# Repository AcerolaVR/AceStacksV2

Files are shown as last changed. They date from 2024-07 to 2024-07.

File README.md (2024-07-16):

# AceStacks v2
A compact, easy-to-assemble SlimeVR tracker design using a PCB with attached sensor and charge circuitry, and the commonly available 16340 battery.

# Overview
AceStacks V2 is a compact, easy-to-assemble SlimeVR tracker design using a PCB with attached sensor and charge circuitry, a D1 Mini, and the commonly available 16340 battery. Here are some of the standout features of the AceStacks trackers.

- The use of the included pin sockets of the D1 Mini allows the MCU to mount over other components, resulting in a compact PCB footprint.
- The design of the board reduces the number of pin headers that need to be trimmed, one of the more annoying parts of DIY trackers with PCBs.
- 16340 cells are easier to obtain (in the United States, not sure about the rest of the world), relatively cheap, more durable compared to li-po pouch cells, and hot swappable if you need more battery life
- This arrangement allows for a compact full body tracker with ~8 hours of battery life, battery sense, AUX tracker support, and a hot swappable battery.

# Parts
Refer to the Official SlimeVR Component Guide for more info https://docs.slimevr.dev/diy/components-guide.html

## Required Parts
- AceStacks V2 PCB
- Microcontroller: Wemos D1 Mini // https://www.aliexpress.com/w/wholesale-D1-mini.html
- Batteries: 16450 Li-ion Batteries // https://illumn.com/16340-vapcell-inr16340-t8-850mah-3a-high-discharge-button-top.html or https://liionwholesale.com/products/vapcell-t8-16340-rcr123a-3a-button-top-850mah-battery-genuine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
- Straps: 1.5in or 38mm Straps // https://www.aliexpress.us/item/3256801722425879.html or https://www.aliexpress.us/item/3256802873749389.html
- 3d Printed Cases

## Extension Parts
- JST ZH1.5 4P, Straight Pin to Pin // [https://www.aliexpress.us/item/3256802896025388.html](https://www.aliexpress.us/item/2251832672911708.html)
# Ordering
You can order bare PCBs here: https://ko-fi.com/s/a833b35730
You can order complete Acestacks V2 Kits Here: https://ko-fi.com/s/f68f3c7944

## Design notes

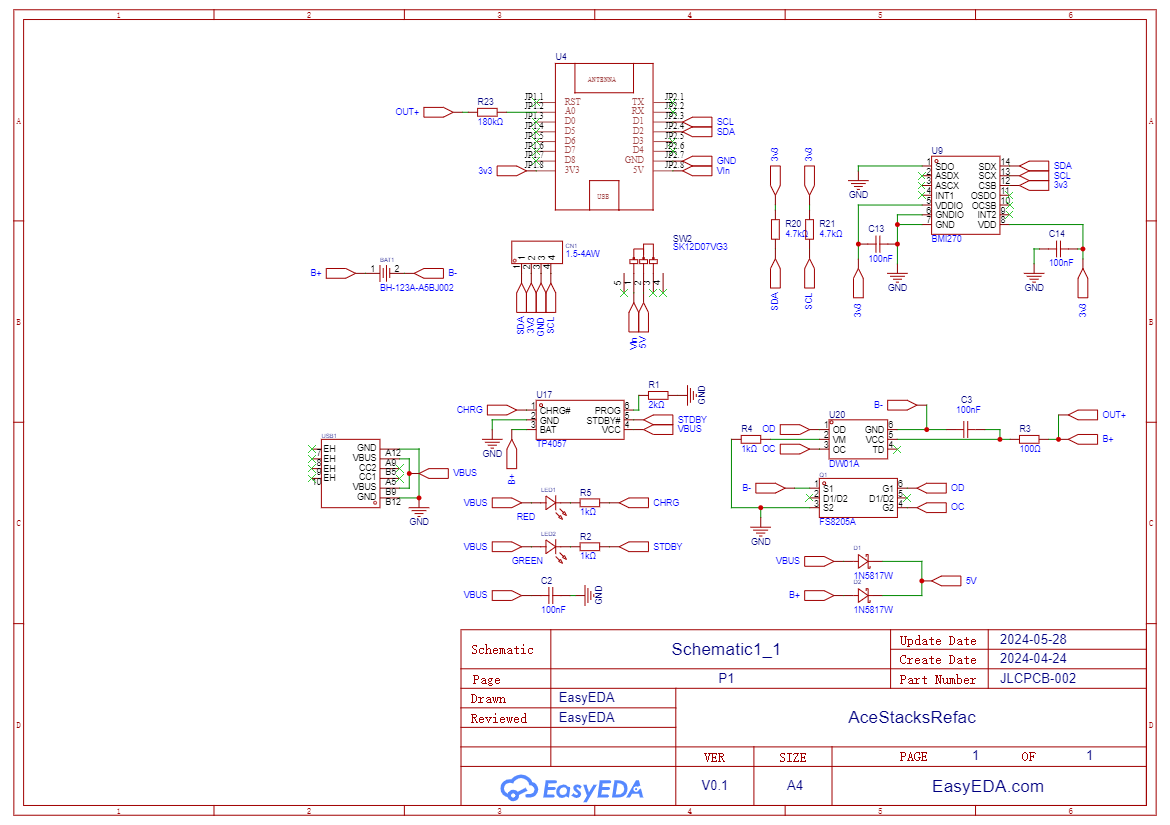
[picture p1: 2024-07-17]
SCHEMATIC/Schematic.png

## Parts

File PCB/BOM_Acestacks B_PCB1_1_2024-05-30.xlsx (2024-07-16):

No. | Quantity | Comment | Designator | Footprint | Value | Manufacturer Part | Manufacturer | Supplier Part | Supplier
1 | 1 | BH-123A-A5BJ002 | BAT1 | BAT-TH_BH-123A-A5BJ002 |  | BH-123A-A5BJ002 | MYOUNG(美阳) | C5290177 | LCSC
2 | 4 | 100nF | C2,C3,C13,C14 | C0603 | 100nF | CC0603KRX7R9BB104 | YAGEO(国巨) | C14663 | LCSC
3 | 1 | 1.5-4AW | CN1 | CONN-TH_4P-P1.50_ZH1.5-4AW |  | 1.5-4AW | BOOMELE(博穆精密) | C146006 | LCSC
4 | 2 | 1N5817W | D1,D2 | SOD-123_L2.8-W1.8-LS3.7-RD |  | 1N5817W | TWGMC(台湾迪嘉) | C727113 | LCSC
5 | 1 | RED | LED1 | LED0603-RD_RED |  | XL-1608SURC-06 | XINGLIGHT(成兴光) | C965799 | LCSC
6 | 1 | GREEN | LED2 | LED0603-RD_GREEN |  | XL-1608UGC-04 | XINGLIGHT(成兴光) | C965804 | LCSC
7 | 1 | FS8205A | Q1 | SOT-23-6_L2.9-W1.6-P0.95-LS2.8-BR |  | FS8205A | FUXINSEMI(富芯森美) | C908265 | LCSC
8 | 1 | 2kΩ | R1 | R0603 | 2kΩ | 0603WAF2001T5E | UNI-ROYAL(厚声) | C22975 | LCSC
9 | 3 | 1kΩ | R2,R4,R5 | R0603 | 1kΩ | 0603WAF1001T5E | UNI-ROYAL(厚声) | C21190 | LCSC
10 | 1 | 100Ω | R3 | R0603 | 100Ω | 0603WAF1000T5E | UNI-ROYAL(厚声) | C22775 | LCSC
11 | 2 | 4.7kΩ | R20,R21 | R0603 | 4.7kΩ | 0603WAF4701T5E | UNI-ROYAL(厚声) | C23162 | LCSC
12 | 1 | 180kΩ | R23 | R0603 | 180kΩ | RTT03184JTP | RALEC(旺诠) | C103362 | LCSC
13 | 1 | SK12D07VG3 | SW2 | SW-TH_SK12D07VG3 |  | SK12D07VG3 | SHOU HAN(首韩) | C431547 | LCSC
14 | 1 | D1-MINI | U4 | D1-MINI
15 | 1 | BMI270 | U9 | LGA-14_L3.0-W2.5-P0.50-BR |  | BMI270 | Bosch(博世) | C2836813 | LCSC
16 | 1 | TP4057 | U17 | SOT-23-6_L2.9-W1.6-P0.95-LS2.8-BR |  | TP4057 | UMW(友台半导体) | C725791 | LCSC
17 | 1 | DW01A | U20 | SOT-23-6_L2.9-W1.6-P0.95-LS2.8-BL |  | DW01A | PUOLOP(迪浦) | C351410 | LCSC
18 | 1 | U262-061N-4BVC11 | USB1 | USB-SMD_U262-061N-4BVC11 |  | U262-061N-4BVC11 | XKB Connectivity(中国星坤) | C2764612 | LCSC

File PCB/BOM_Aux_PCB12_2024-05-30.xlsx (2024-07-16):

No. | Quantity | Comment | Designator | Footprint | Value | Manufacturer Part | Manufacturer | Supplier Part | Supplier
1 | 2 | 100nF | C13,C14 | C0603 | 100nF | CC0603KRX7R9BB104 | YAGEO(国巨) | C14663 | LCSC
2 | 1 | 1.5-4AW | CN1 | CONN-TH_4P-P1.50_ZH1.5-4AW |  | 1.5-4AW | BOOMELE(博穆精密) | C146006 | LCSC
3 | 3 | 4.7kΩ | R20,R22,R23 | R0603 | 4.7kΩ | 0603WAF4701T5E | UNI-ROYAL(厚声) | C23162 | LCSC
4 | 1 | BMI270 | U9 | LGA-14_L3.0-W2.5-P0.50-BR |  | BMI270 | Bosch(博世) | C2836813 | LCSC

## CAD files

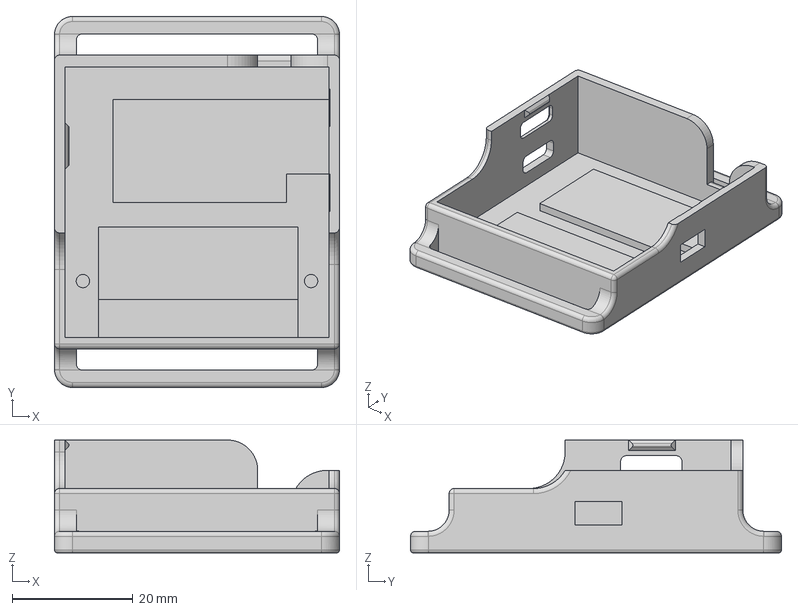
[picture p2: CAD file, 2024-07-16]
STEP/StandardCase.step
47.2 x 61.5 x 18.7 mm

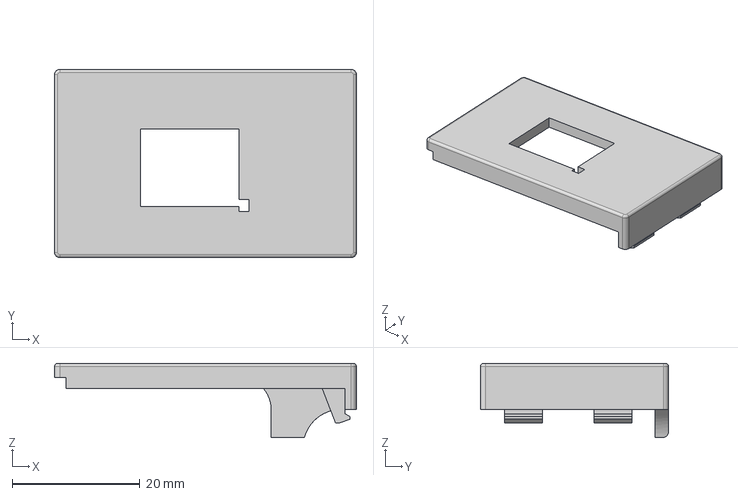
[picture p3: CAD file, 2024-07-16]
STEP/Lid.step
47.2 x 29.5 x 11.6 mm

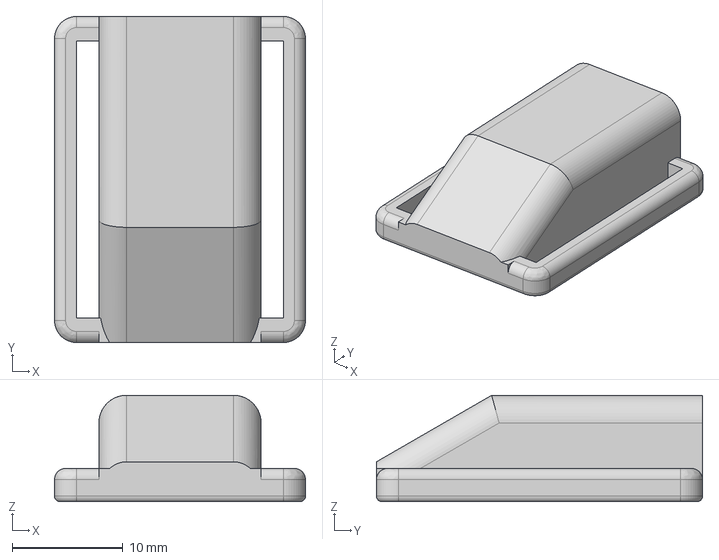
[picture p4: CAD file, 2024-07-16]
STEP/BMI270.step
22.6 x 29.4 x 9.60 mm

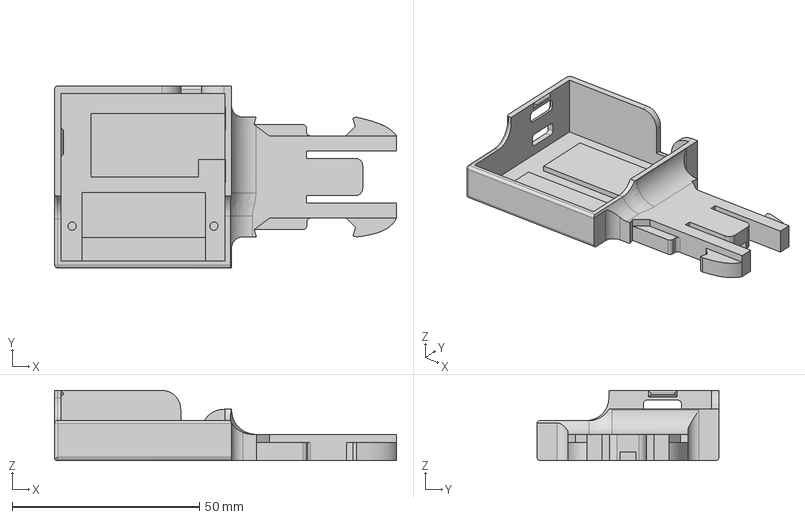
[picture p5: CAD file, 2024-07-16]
STEP/GoProCase.step
91.2 x 48.7 x 18.7 mm

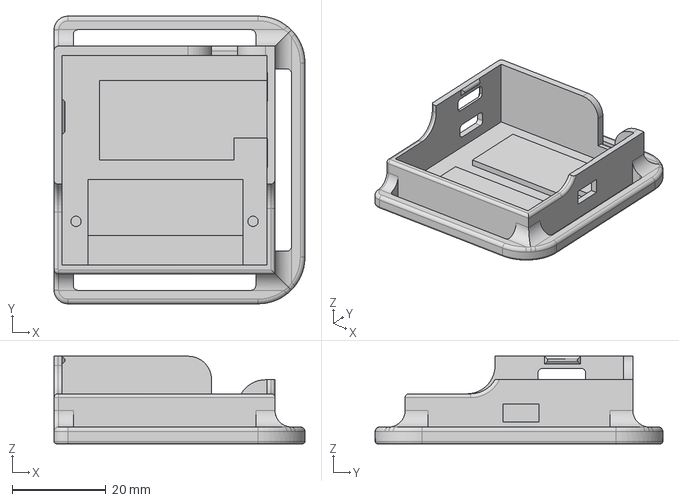
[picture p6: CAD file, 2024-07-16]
STEP/GarterCase.step
53.6 x 61.5 x 18.7 mm

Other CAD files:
STL/BMI270.stl
STL/GarterCase.stl
STL/GoProCase.stl
STL/Lid.stl
STL/StandardCase.stl

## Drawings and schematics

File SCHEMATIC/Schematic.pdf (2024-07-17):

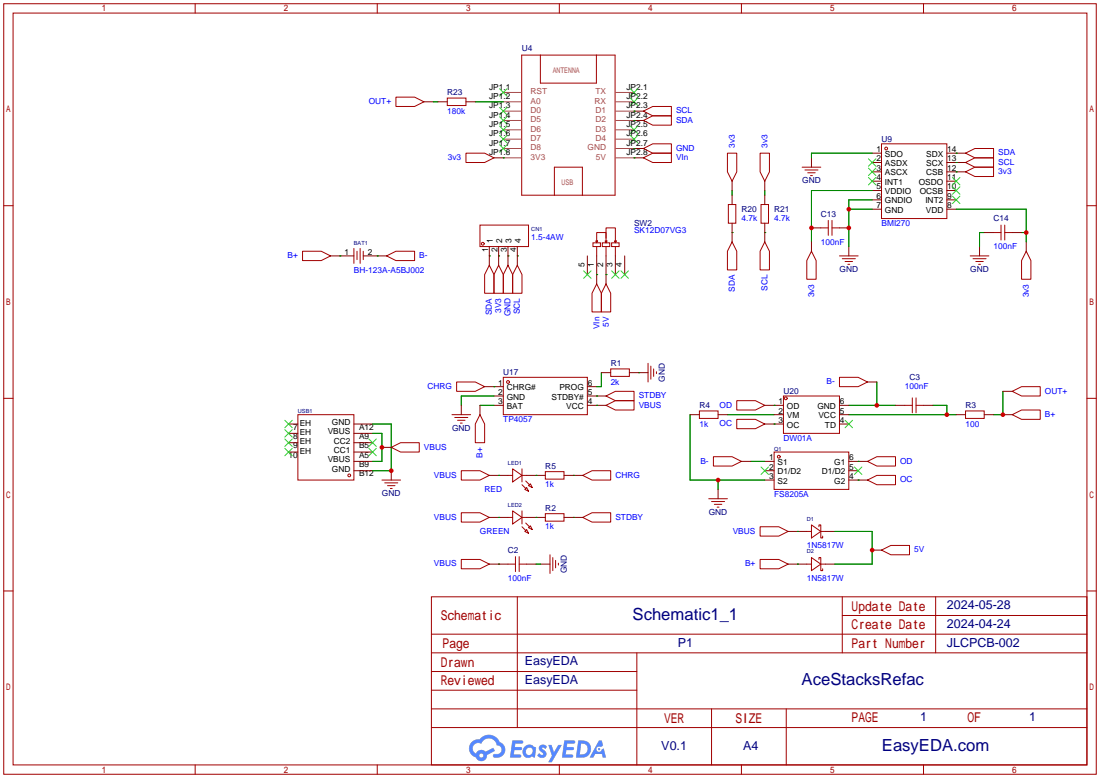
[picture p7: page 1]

OCSB 10 OSDO 11 CSB 12 SCX 13 SDX 14
